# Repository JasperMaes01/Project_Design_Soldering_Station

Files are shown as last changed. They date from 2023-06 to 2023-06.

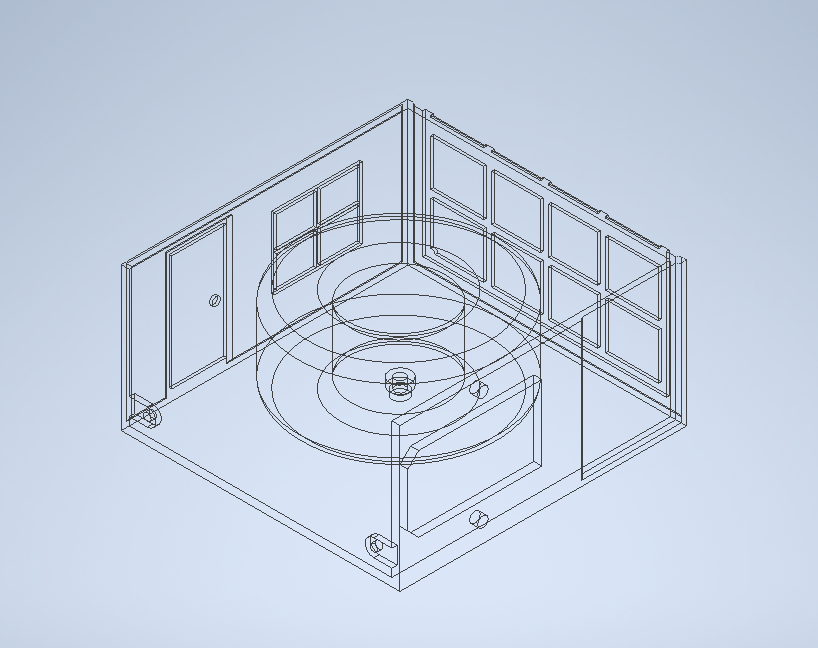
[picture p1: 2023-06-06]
3D-design/Pictures of the design/Assembly (2).png

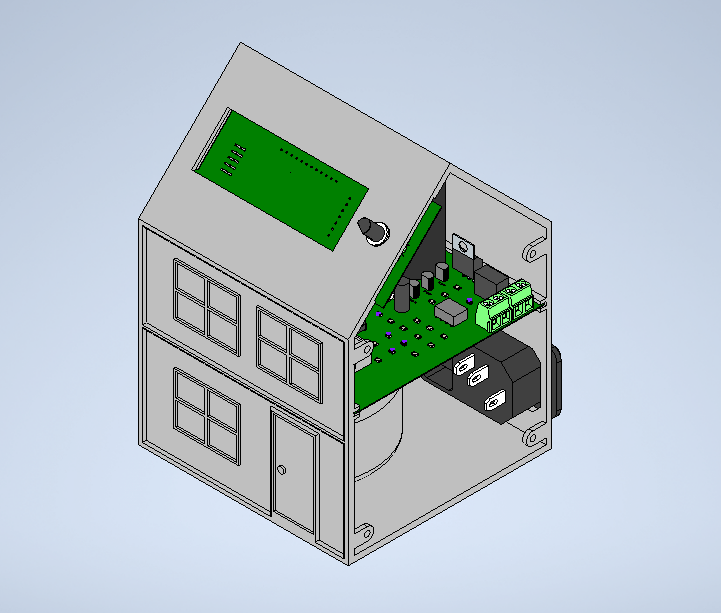
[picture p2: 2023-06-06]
3D-design/Pictures of the design/Assembly (6).png

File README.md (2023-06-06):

# Project_Design_Soldering_Station
## About this project
This project is the complete assembly of a DIY soldering station. Everything is explained in the Applicaton note (to be fount under documentation).

The finished product will be able to drive a soldering iron based on user's selected value, to be seen on the display. The fully self-designed PCB (Printed Circuit Board) can read the temperature sensor located in the soldering iron. This information will be used to control the bolt temperature based on the user's set-ting. As a result, the soldering iron will maintain the desired temperature.

This project includes some basic circuitry, such as transistor circuits. However, it is not an overly complex circuit, which makes it an ideal way to get familiar with PCB design. Moreover, the final product is also useful, so it isn't a waste of money. 

The project is based on an example from the 'Elektor' magazine. They already provided a schematic that was tested and worked without error. Based on this schematic, the soldering station being described here was made.

## Documentation
Under documentation, the BOM (Bill Off Materials) and the Application note can be found.

In the 3D design folder, the whole 3D design of the case can be found.

## 3D design
(more pictures can be found under 3D-design/Pictures_of_the_design)

Schermafbeelding 2023-05-29 215436

^^The front view of the 3D design.

Schermafbeelding 2023-05-29 215131 Schermafbeelding 2023-05-29 215413

^^No PCB screws are needed, the PCBs can be slit into a slot, or clicked into a nice clicking system.

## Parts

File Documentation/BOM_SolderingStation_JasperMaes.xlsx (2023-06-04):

Name | Description | Designator | Quantity | Total price | ordered from
D6KB6U | Bridge Rectifier Diode 15A 800V GSIB-5S | B1, B2 | 2 | €1.66
4700µ - 50V | Aluminum Electrolytic Capacitors (Radial Lead Type) 100uF ±20% 25V | C1 | 1 | €4.20
10µF | CAP CER 0.1UF 50V X7R 0805 | C1O | 1 | €2.75
100µ - 50V | Aluminum Electrolytic Capacitors (Radial Lead Type) 100uF ±20% 25V | C1.1 | 1 | €0.52
100n | CAP CER 0.1UF 50V X7R 0805 | C1.2, C3 | 2 | €0.00 | At school
10n | CAP CER 0.1UF 50V X7R 0805 | C1.3, C1.4, C1.5, C6, C7, C12, C13 | 7 | €0.00 | At school
10µ - 50V | Aluminum Electrolytic Capacitors (Radial Lead Type) 100uF ±20% 25V | C2, C5 | 2 | €5.50
100µ - 25V | Aluminum Electrolytic Capacitors (Radial Lead Type) 100uF ±20% 25V | C4 | 1 | €0.52
100nF | CAP CER 0.1UF 50V X7R 0805 | C8, C9, C11, C14 | 4 | €0.00 | At school
1N4007 | Rectifier diode 1000 V 1 A DO-41, , | D1, D3 | 2 | €0.22
5V1 | Zener Voltage Regulator, 500 mW, 2-Pin SOD-123, Pb-Free, Tape and Reel | D2 | 1 | €0.17
PEC11R-4215F-S0024 | ROTARY ENCODER MECHANICAL 24PPR | ENC1 | 1 | €3.29
OKI-78SR-5/1.5-W36-C | Non-Isolated DC/DC Converter, 7.5 W, 7 to 36 V, 1.5 A, -40 to 85 degC, 3-Pin THD, RoHS | IC1 | 1 | €20.25 | rs components
TM1637 | LED Drive Control Special Circuit | IC1.1 | 1 | €8.00 | AMAZON
MCP6002-E/P | None | IC2 | 1 | €0.58
ATMEGA4809-PF | IC MCU 8BIT 48KB FLASH 40DIP | IC3 | 1 | €3.12
1729128 | PCB Terminal Block, 13.5 A, 400 V, 2-Pin THD, RoHS, Bulk | K1, K2, K3, K8 | 4 | €3.20
1-1634688-0 | Male Header, Pitch 2.54 mm, 2 x 5 Postion, Height 9.15 mm, Tail Length 3.2 mm, -40 to 105 degC, RoHS, Bulk | K1.1 | 1 | €0.00 | At school
 | Male Header, Pitch 2.54 mm, 1 x 3 Position, Height 8.38 mm, Tail Length 3.18 mm, RoHS, Bulk | K4, K7 | 2 | €0.00 | At school
 | Male Header, Pitch 2.54 mm, 1 x 2 Position, Height 8.21 mm, Tail Length 3.05 mm, -65 to 105 degC, RoHS, Bulk | K5 | 1 | €0.00 | At school
UART2 | THT Vertical Pin Header WR-PHD, Pitch 2.54 mm, Single Row, 4 pins | K6 | 1 | €0.00 | At school
691701320005B | Serie 7013 B - 3.81mm Vertical PCB Header THR Type with Flanges WR-TBL, 5 pin | K9 | 1 | €2.88
UART0 | Male Header, Pitch 2.54 mm, 1 x 3 Position, Height 8.38 mm, Tail Length 3.18 mm, RoHS, Bulk | K10 | 1 | €0.00 | At school
610106249121 | SMT Angled Pin Header WR-PHD, Pitch 2.54 mm, Dual Row, 6 pins | K11 | 1 | €0.00 | At school
 | Male Header, Pitch 2.54 mm, 2 x 5 Postion, Height 9.15 mm, Tail Length 3.2 mm, -40 to 105 degC, RoHS, Bulk | K12 | 1 | €0.00 | At school
10µH | IR-2 10 10% B08 | L1 | 1 | €5.50
 | Common Mode Chokes Dual 170Ohm 100MHz 10A 0.01Ohm DCR Thru-Hole Bulk | L2 | 1 | €1.50
KW4-801AVB | Display, Seven Segment, 9.2MM, Red | LD1 | 1 | €1.80 | TME
18K |  | R1, R11, R12 | 3 | €0.00 | At school
10K |  | R1.1, R1.2, R1.3, R6, R7 | 5 | €0.00 | At school
1M |  | R2 | 1 | €0.00 | At school
68K |  | R3 | 1 | €0.00 | At school
5K6 |  | R4, R5, R13, R14 | 4 | €0.00 | At school
100E |  | R8, R15, R18 | 3 | €0.00 | At school
10M |  | R9 | 1 | €0.00 | At school
4,7K |  | R10, R17, R20 | 3 | €0.00 | At school
4.7K |  | R16 | 1 | €0.00 | At school
10k |  | R19 | 1 | €0.00 | At school
4,7k |  | R21, R22 | 2 | €0.00 | At school
RT424005F | RELAY GENERAL PURPOSE DPDT 8A 5V | RE1 | 1 | €3.32
BC547 | Amplifier Transistor, NPN Silicon, 3-Pin TO-92, Pb-Free, Bulk Box | T1 | 1 | €0.52
BC547CG | Amplifier Transistor, NPN Silicon, 3-Pin TO-92, Pb-Free, Bulk Box | T2, T4 | 2 | €1.03
IRF9Z34NPBF | MOSFET MOSFT PCh -55V -17A 100mOhm 23.3nC | T3 | 1 | €1.15
BC557C | Amplifier Transistor, PNP Silicon, 3-Pin TO-92, Bulk Box | T5 | 1 | €0.12
TST 60/002INDEL (https://www.tme.eu/nl/katalog/toroidale-transformatoren_100028/p,indel_337/) | toroidal transformer 60VA | external | 1 | €27.48
 |  |  | Total price: | €99.28

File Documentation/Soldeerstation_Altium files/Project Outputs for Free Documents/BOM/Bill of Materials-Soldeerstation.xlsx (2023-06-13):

Line # | Name | Description | Designator | Quantity | Manufacturer 1 | Manufacturer Part Number 1 | Manufacturer Lifecycle 1 | Supplier 1 | Supplier Part Number 1 | Supplier Unit Price 1 | Supplier Subtotal 1
 | D6KB6U | Bridge Rectifier Diode 15A 800V GSIB-5S | B1, B2 | 2
 | 4700µ - 50V | Aluminum Electrolytic Capacitors (Radial Lead Type) 100uF ±20% 25V | C1 | 1
 | 10µF | CAP CER 0.1UF 50V X7R 0805 | C1O | 1
 | 100µ - 50V | Aluminum Electrolytic Capacitors (Radial Lead Type) 100uF ±20% 25V | C1.1 | 1
 | 100n | CAP CER 0.1UF 50V X7R 0805 | C1.2, C3 | 2
 | 10n | CAP CER 0.1UF 50V X7R 0805 | C1.3, C1.4, C1.5, C6, C7, C12, C13 | 7
 | 10µ - 50V | Aluminum Electrolytic Capacitors (Radial Lead Type) 100uF ±20% 25V | C2, C5 | 2
 | 100µ - 25V | Aluminum Electrolytic Capacitors (Radial Lead Type) 100uF ±20% 25V | C4 | 1
 | 100nF | CAP CER 0.1UF 50V X7R 0805 | C8, C9, C11, C14 | 4
 | 1N4007 | Rectifier diode 1000 V 1 A DO-41, , | D1, D3 | 2
 | 5V1 | Zener Voltage Regulator, 500 mW, 2-Pin SOD-123, Pb-Free, Tape and Reel | D2 | 1
 | PEC11R-4215F-S0024 | ROTARY ENCODER MECHANICAL 24PPR | ENC1 | 1
 | OKI-78SR-5/1.5-W36-C | Non-Isolated DC/DC Converter, 7.5 W, 7 to 36 V, 1.5 A, -40 to 85 degC, 3-Pin THD, RoHS | IC1 | 1
 | TM1637 | LED Drive Control Special Circuit | IC1.1 | 1
 | MCP6002-E/P | None | IC2 | 1
 | ATMEGA4809-PF | IC MCU 8BIT 48KB FLASH 40DIP | IC3 | 1
 | 1729128 | PCB Terminal Block, 13.5 A, 400 V, 2-Pin THD, RoHS, Bulk | K1, K2, K3, K8 | 4
 | 1-1634688-0 | Male Header, Pitch 2.54 mm, 2 x 5 Postion, Height 9.15 mm, Tail Length 3.2 mm, -40 to 105 degC, RoHS, Bulk | K1.1 | 1
 |  | Male Header, Pitch 2.54 mm, 1 x 3 Position, Height 8.38 mm, Tail Length 3.18 mm, RoHS, Bulk | K4, K7 | 2
 |  | Male Header, Pitch 2.54 mm, 1 x 2 Position, Height 8.21 mm, Tail Length 3.05 mm, -65 to 105 degC, RoHS, Bulk | K5 | 1
 | UART2 | THT Vertical Pin Header WR-PHD, Pitch 2.54 mm, Single Row, 4 pins | K6 | 1
 | 691701320005B | Serie 7013 B - 3.81mm Vertical PCB Header THR Type with Flanges WR-TBL, 5 pin | K9 | 1
 | UART0 | Male Header, Pitch 2.54 mm, 1 x 3 Position, Height 8.38 mm, Tail Length 3.18 mm, RoHS, Bulk | K10 | 1
 | 610106249121 | SMT Angled Pin Header WR-PHD, Pitch 2.54 mm, Dual Row, 6 pins | K11 | 1
 |  | Male Header, Pitch 2.54 mm, 2 x 5 Postion, Height 9.15 mm, Tail Length 3.2 mm, -40 to 105 degC, RoHS, Bulk | K12 | 1
 | 10µH | IR-2 10 10% B08 | L1 | 1
 |  | Common Mode Chokes Dual 170Ohm 100MHz 10A 0.01Ohm DCR Thru-Hole Bulk | L2 | 1
 | KW4-801AVB | Display, Seven Segment, 9.2MM, Red | LD1 | 1
 | 18K |  | R1, R11, R12 | 3
 | 10K |  | R1.1, R1.2, R1.3, R6, R7 | 5
 | 1M |  | R2 | 1
 | 68K |  | R3 | 1
 | 5K6 |  | R4, R5, R13, R14 | 4
 | 100E |  | R8, R15, R18 | 3
 | 10M |  | R9 | 1
 | 4,7K |  | R10, R17, R20 | 3
 | 4.7K |  | R16 | 1
 | 10k |  | R19 | 1
 | 4,7k |  | R21, R22 | 2
 | RT424005F | RELAY GENERAL PURPOSE DPDT 8A 5V | RE1 | 1
 | BC547 | Amplifier Transistor, NPN Silicon, 3-Pin TO-92, Pb-Free, Bulk Box | T1 | 1
 | BC547CG | Amplifier Transistor, NPN Silicon, 3-Pin TO-92, Pb-Free, Bulk Box | T2, T4 | 2
 | IRF9Z34NPBF | MOSFET MOSFT PCh -55V -17A 100mOhm 23.3nC | T3 | 1
 | BC557C | Amplifier Transistor, PNP Silicon, 3-Pin TO-92, Bulk Box | T5 | 1

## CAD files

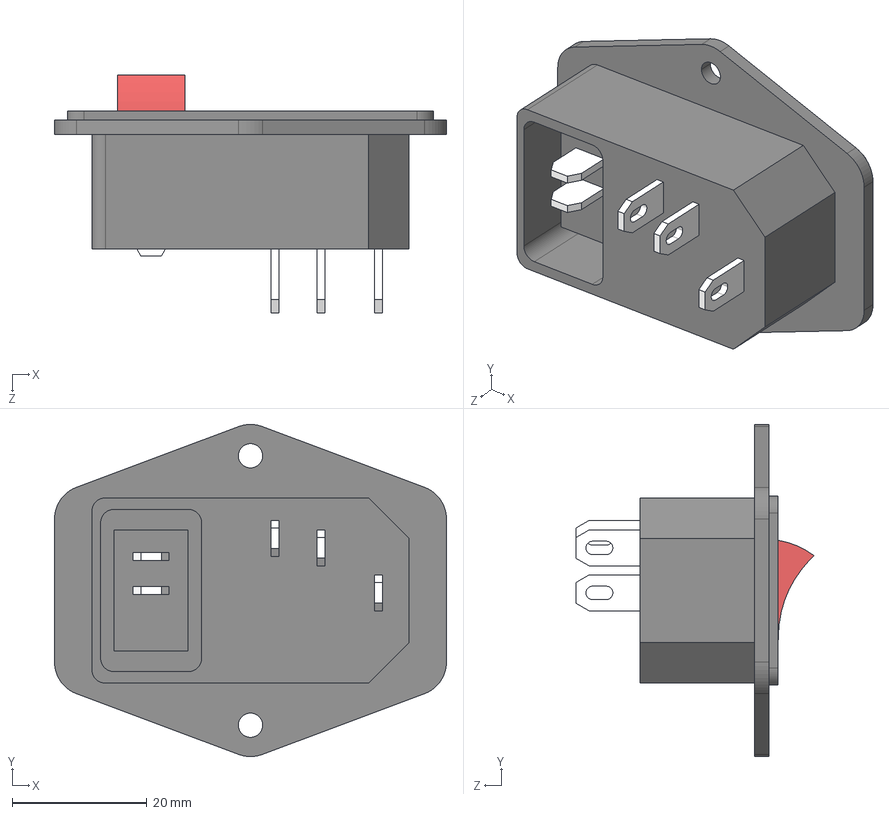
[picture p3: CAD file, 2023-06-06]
3D-design/Inventor files/SolderingStation_Files/power connector.STEP
58.2 x 49.3 x 35.4 mm

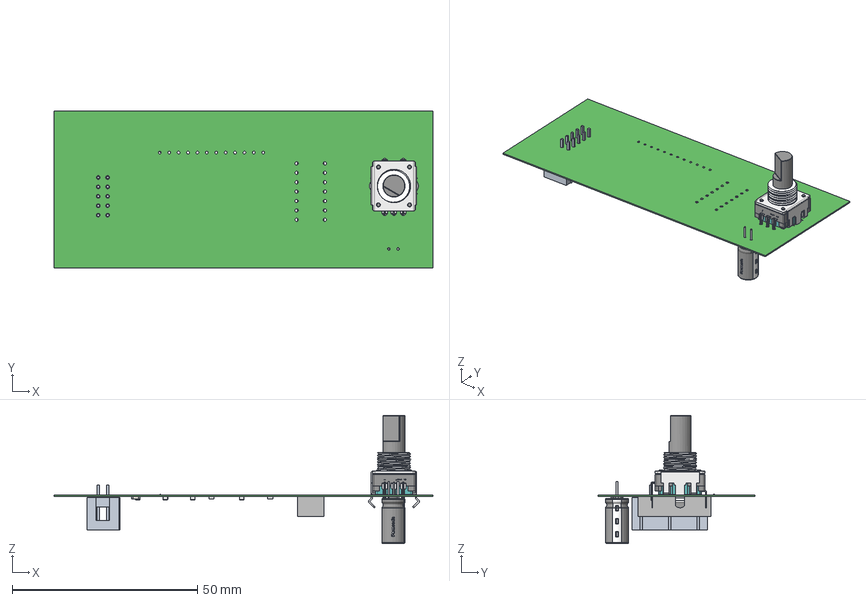
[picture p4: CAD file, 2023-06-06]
3D-design/Inventor files/SolderingStation_Files/PCB2.step
102.4 x 42.3 x 34.6 mm
Extruded x 11
c-1634688-10-c-3d
pec12r-3x17f-sxxxx
Bourns Logo
Cap_KEMET_C0805C472J3HAC_eec x 12
marking
bottom
logo
polarity marking
top
terminal

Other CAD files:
3D-design/Inventor files/SoldeerstationAssambly.iam
3D-design/Inventor files/SolderingStation_Files/022284033.iam
3D-design/Inventor files/SolderingStation_Files/1.iam
3D-design/Inventor files/SolderingStation_Files/1.ipt
3D-design/Inventor files/SolderingStation_Files/10.ipt
3D-design/Inventor files/SolderingStation_Files/1729128.iam
3D-design/Inventor files/SolderingStation_Files/2.ipt
3D-design/Inventor files/SolderingStation_Files/3.ipt
3D-design/Inventor files/SolderingStation_Files/4.ipt
3D-design/Inventor files/SolderingStation_Files/5.ipt
3D-design/Inventor files/SolderingStation_Files/6.ipt
3D-design/Inventor files/SolderingStation_Files/6065959632.iam
3D-design/Inventor files/SolderingStation_Files/6065959792.iam
3D-design/Inventor files/SolderingStation_Files/61300411121.iam
3D-design/Inventor files/SolderingStation_Files/61300411121.ipt
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

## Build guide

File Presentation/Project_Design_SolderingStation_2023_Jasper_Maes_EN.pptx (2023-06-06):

## Project design - Soldering station

Jasper Maes
1EAI

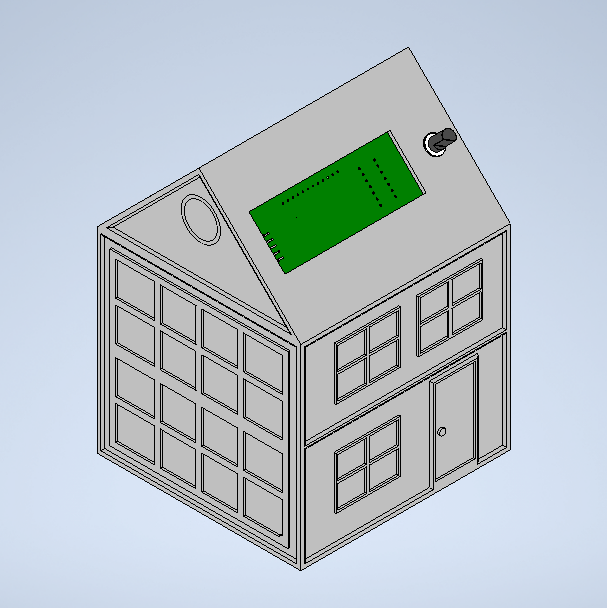
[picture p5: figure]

## Table of contents

- Goal of this project
- Schematic design
- PCB design
- Components
- Errors
- 3D case design
- Reflection

## Goal of this project

- Learning to:
  - Design in Altium designer
  - Design in Inventor/Fusion 360
  - Mount PCBs
  - Troubleshoot

## Schematic design

- Altium Designer
- Consists of 5 parts
  - Soldering iron controller
  - Power supply (2 X 12 V inlet)
  - Temperature measurement
  - Main IC schematic
  - Display board

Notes: Controller == power is sent to the soldering iron
ATMEG placed on main IC = ATMEG = main microcontroller

## PCB design

- Altium
- Based on schematic
- Autorouting (still some errors)
- Ordered at JLC
- 35,36 euros (shipping included)

## Components

- BOM (see GitHub)
- Mostly ordered at Farnell
- Total price (all components) = 99,28 euros

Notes: Brings the total of the project to: 134,64 euros

## Errors

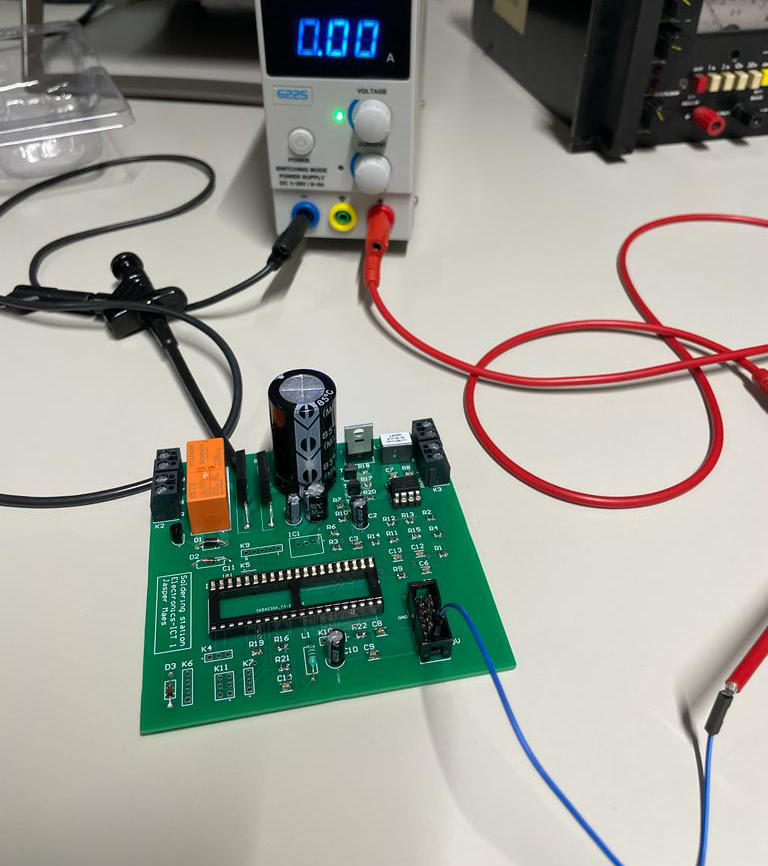
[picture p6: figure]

- Errors in the schematics
  - Lane not drawn (autorouting bug)
  - Wrong footprints
  - Some other unknow bug

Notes: Footprints of: display IC, Bridge rectifiers, capacitor and transistors where wrong

## 3D case design

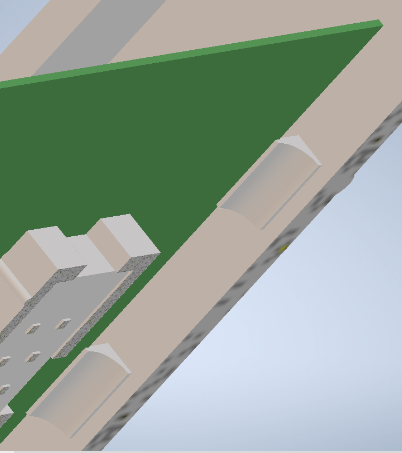
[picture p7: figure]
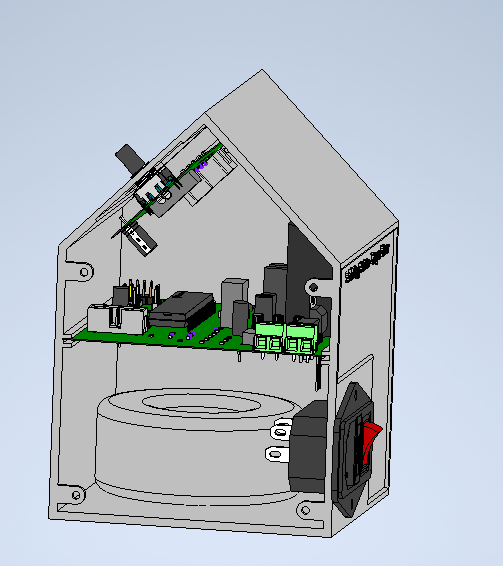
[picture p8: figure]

- Not printed
- No PCB screws
- Closure provided

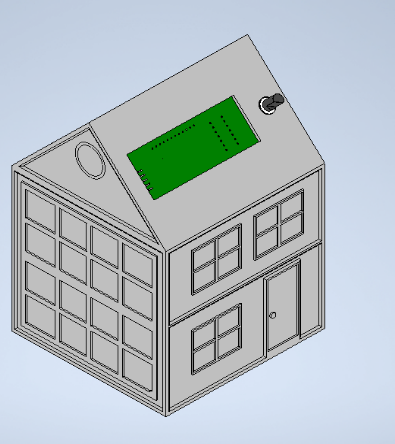
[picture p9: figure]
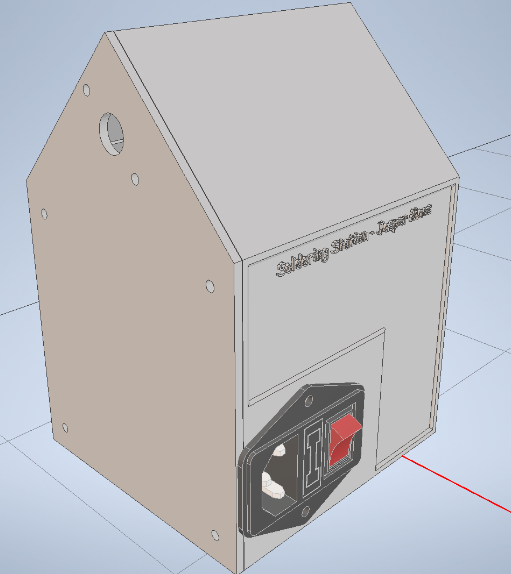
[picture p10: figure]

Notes: First: guitar amp
Then, house (not enough time for amp)
the main print is slid into a slot

## Reflection

- Interesting project
- Still bugs on the PCB

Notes: If the bugs are fixed, the project should work perfectly

## Any questions?

- Thanks for listening

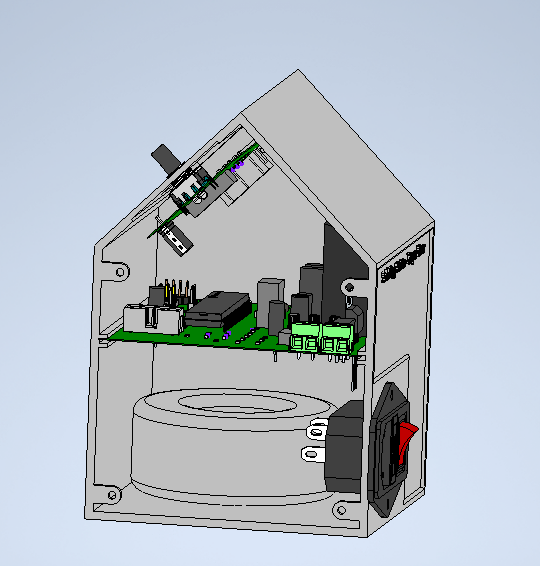
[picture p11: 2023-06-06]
3D-design/Pictures of the design/Assembly (5).png

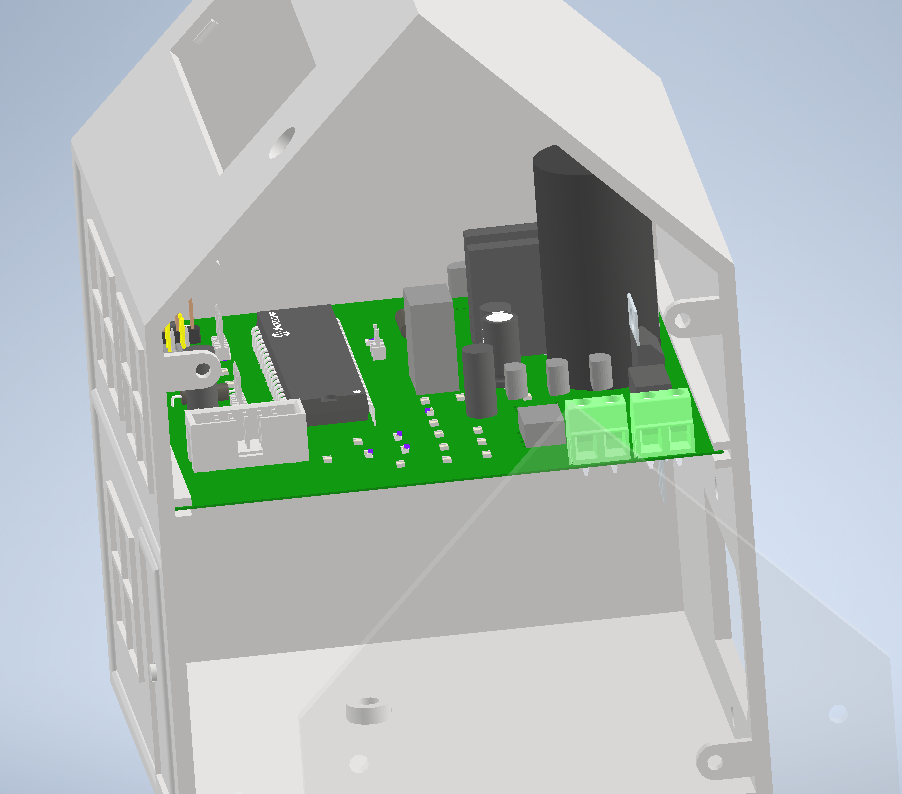
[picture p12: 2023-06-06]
3D-design/Pictures of the design/Assembly (1).png

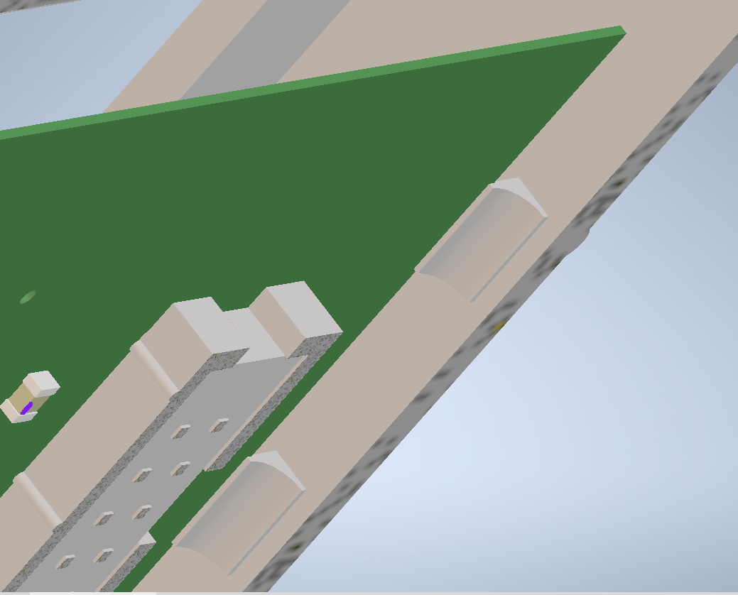
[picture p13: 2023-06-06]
3D-design/Pictures of the design/Assembly (4).png

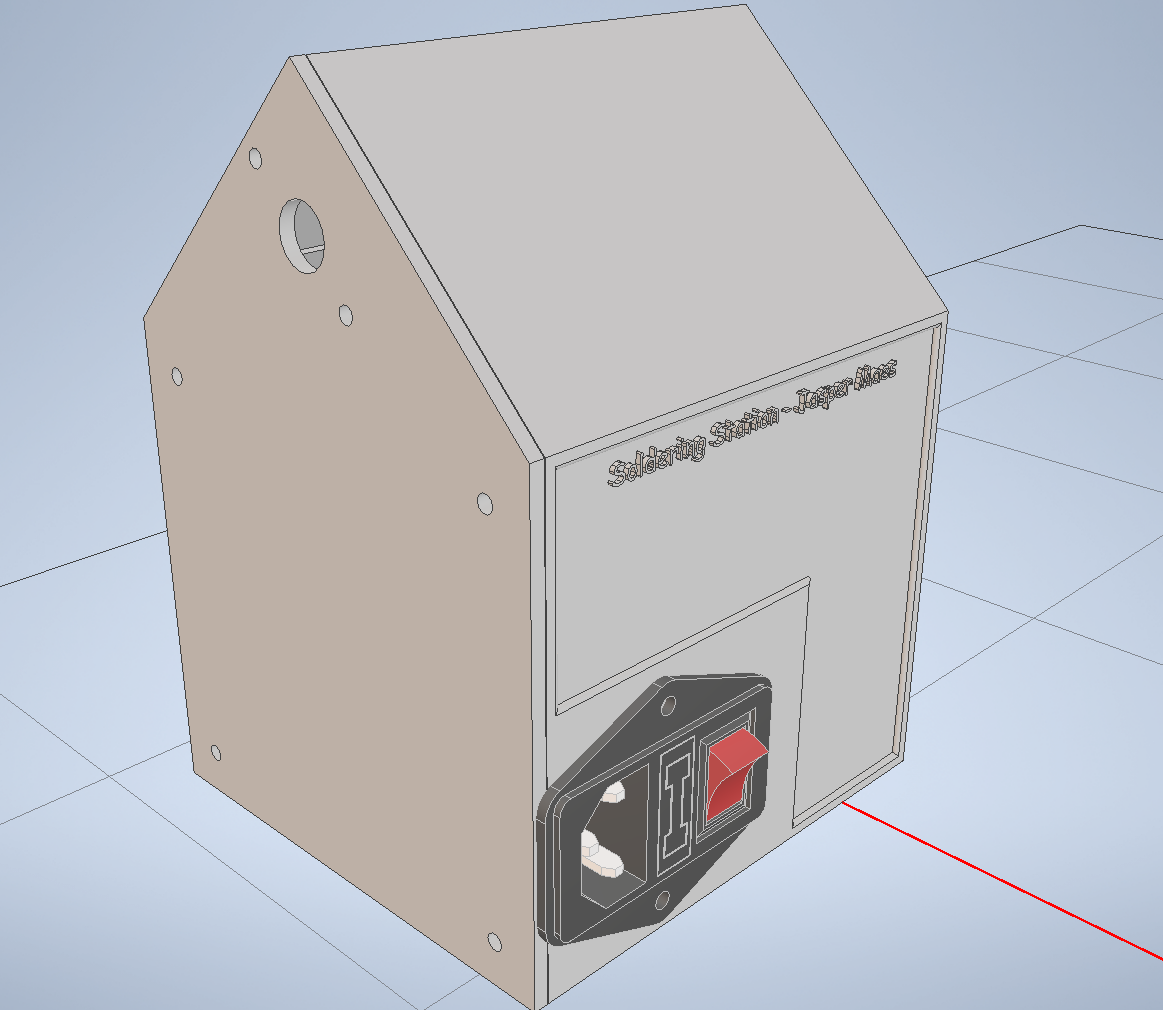
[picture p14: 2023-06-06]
3D-design/Pictures of the design/Assembly (8).png

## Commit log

2023-06-06 Add Inventor files
    [022284033.iam, 1.0001.ipt, 1.iam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]
2023-06-13 Add Altium files
    [Assembly Testpoint Report for PCB3.csv, Bill of Materials-Soldeerstation.xlsx, DisplayPrint.SchDoc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]
